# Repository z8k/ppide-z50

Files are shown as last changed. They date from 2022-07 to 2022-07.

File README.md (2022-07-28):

# ppide-z50
PPIDE card for Z50Bus

Heavily based on https://github.com/electrified/rc2014-82c55-ide

Intended for use with a horizontal-mounting 44-pin IDE Disk-On-Module module, this card omits the 40-pin IDE connector and external power input jack.

Notes:
1. Address selection is with the jumper pins in the lower right. Address bits A1 and A0 are ignored. Set to 0x20 (one jumper, on pin A5) for use with RomWBW and/or Fuzix.
2. You may wish to lower the value of R101 or use a super-bright LED if the disk activity light is a bit dim.

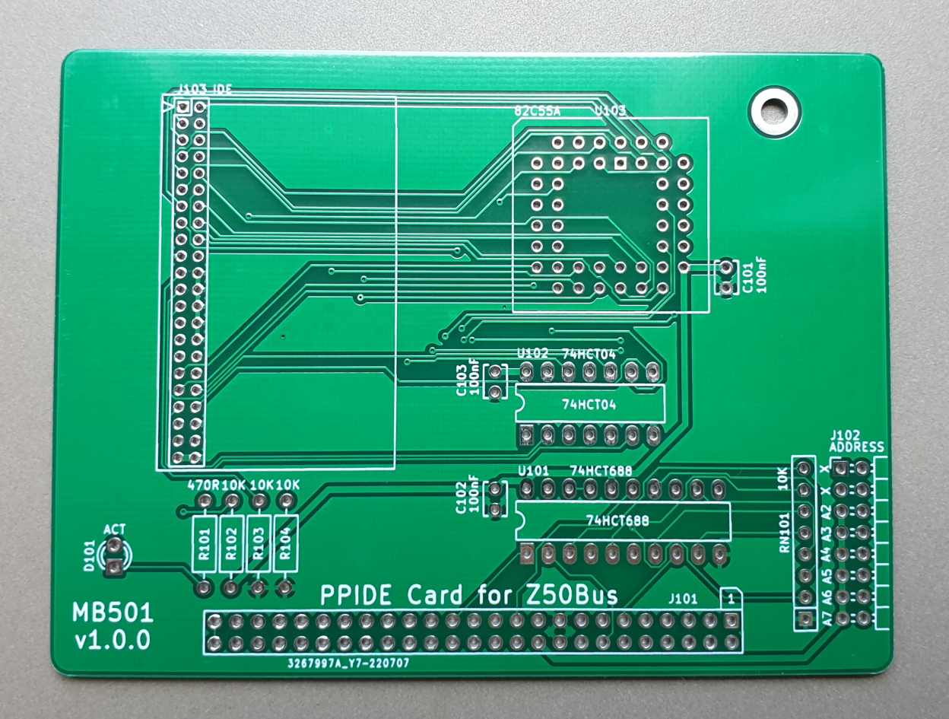
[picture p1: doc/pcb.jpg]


| Reference |  Value |
|---|---|
| R101 | 470R resistor or lower value suitable for your LED |
| R102 | 10K resistor |
| R103 | 10K resistor |
| R104 | 10K resistor |
| C101 | 0.1uF ceramic capacitor |
| C102 | 0.1uF ceramic capacitor |
| C103 | 0.1uF ceramic capacitor |
| RN101 | 10K SIP resistor (8 pins, 7 resistors) |
| D101 | LED |
| U101 | 74HCT688 |
| U102 | 74HCT04 |
| U103 | 82C55A (PLCC package) |
| J101 | 2x25 2.54mm right-angle male box header |
| J102 | 2x8 2.54mm pitch right-angle pin header |
| J103 | 2x22 2mm pitch pin header |

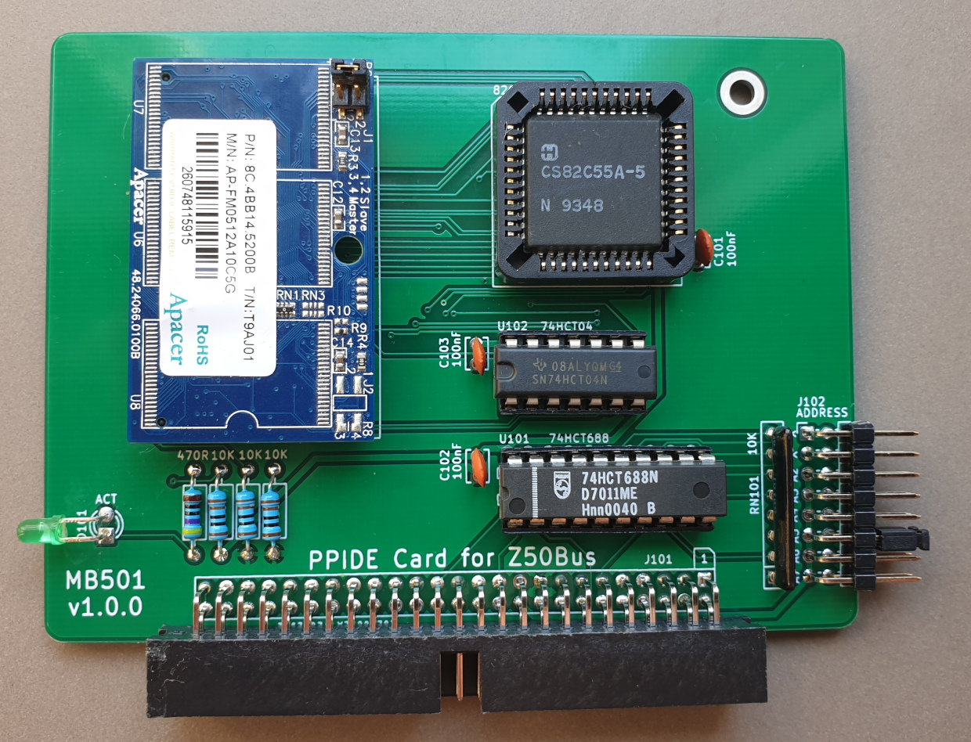
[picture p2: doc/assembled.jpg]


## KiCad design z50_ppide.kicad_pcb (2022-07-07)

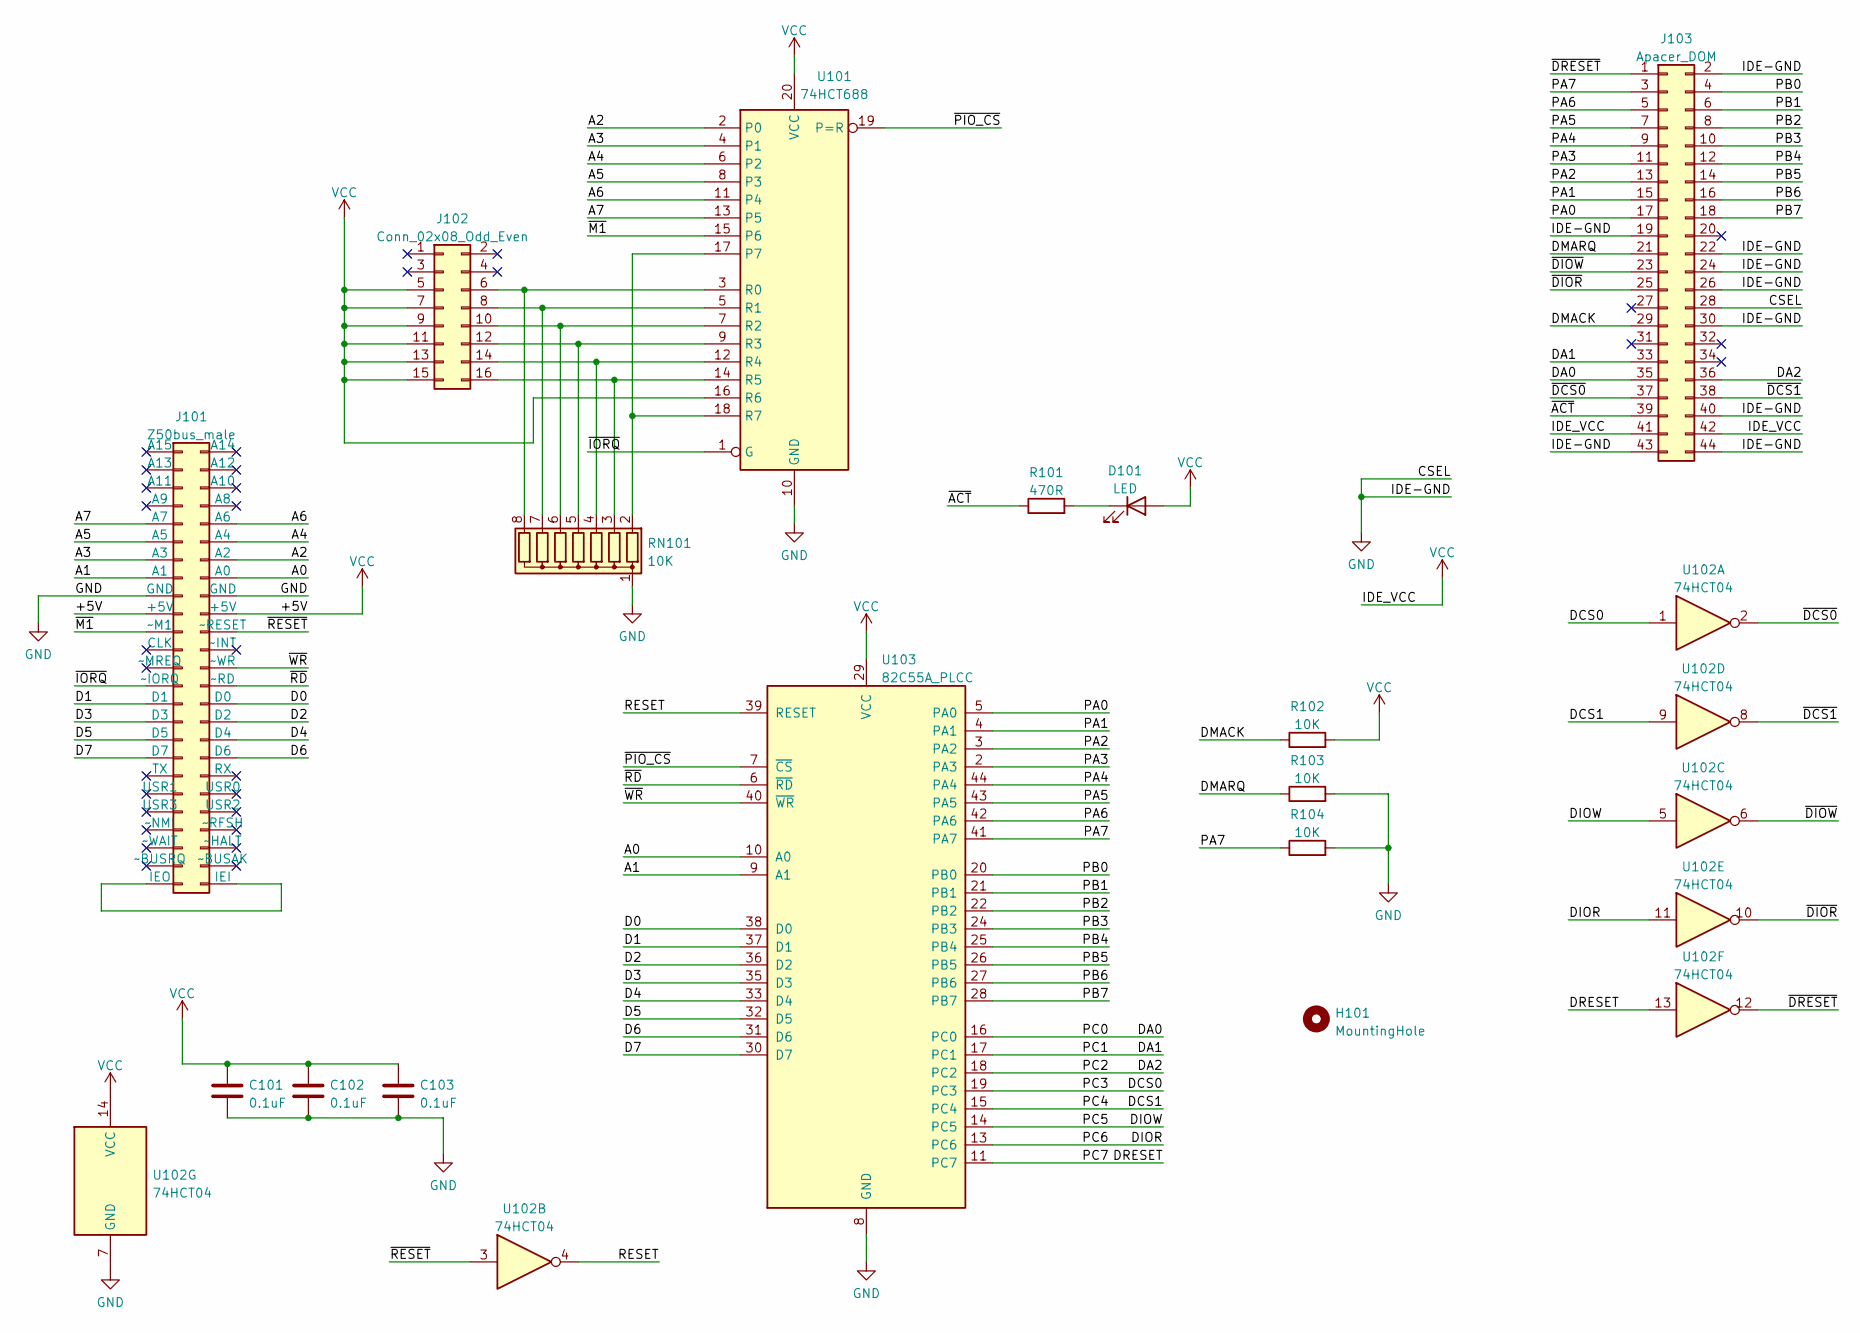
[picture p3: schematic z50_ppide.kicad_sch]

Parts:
C101, C102, C103: 0.1uF; C_Disc_D3.8mm_W2.6mm_P2.50mm
D101: LED; LED_D3.0mm
H101: MountingHole; MountingHole_3.2mm_M3_DIN965_Pad_TopBottom
J101: Z50bus_male; Z50bus module card edge
J102: Conn_02x08_Odd_Even; PinHeader_2x08_P2.54mm_Horizontal
J103: Apacer_DOM; Apacer DOM
R101: 470R; R_Axial_DIN0207_L6.3mm_D2.5mm_P10.16mm_Horizontal
R102, R103, R104: 10K; R_Axial_DIN0207_L6.3mm_D2.5mm_P10.16mm_Horizontal
RN101: 10K; R_Array_SIP8
U101: 74HCT688; DIP-20_W7.62mm_LongPads
U102: 74HCT04; DIP-14_W7.62mm_LongPads
U103: 82C55A_PLCC; PLCC-44_THT-Socket

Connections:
/A0: J101.16 (A0), U103.10 (A0)
/A1: J101.15 (A1), U103.9 (A1)
/A2: J101.14 (A2), U101.2 (P0)
/A3: J101.13 (A3), U101.4 (P1)
/A4: J101.12 (A4), U101.6 (P2)
/A5: J101.11 (A5), U101.8 (P3)
/A6: J101.10 (A6), U101.11 (P4)
/A7: J101.9 (A7), U101.13 (P5)
/D0: J101.30 (D0), U103.38 (D0)
/D1: J101.29 (D1), U103.37 (D1)
/D2: J101.32 (D2), U103.36 (D2)
/D3: J101.31 (D3), U103.35 (D3)
/D4: J101.34 (D4), U103.33 (D4)
/D5: J101.33 (D5), U103.32 (D5)
/D6: J101.36 (D6), U103.31 (D6)
/D7: J101.35 (D7), U103.30 (D7)
/DA0: J103.35, U103.16 (PC0)
/DA1: J103.33, U103.17 (PC1)
/DA2: J103.36, U103.18 (PC2)
/DCS0: U102.1, U103.19 (PC3)
/DCS1: U102.9, U103.15 (PC4)
/DIOR: U102.11, U103.13 (PC6)
/DIOW: U102.5, U103.14 (PC5)
/DMACK: J103.29, R102.1
/DMARQ: J103.21, R103.1
/DRESET: U102.13, U103.11 (PC7)
/PA0: J103.17, U103.5 (PA0)
/PA1: J103.15, U103.4 (PA1)
/PA2: J103.13, U103.3 (PA2)
/PA3: J103.11, U103.2 (PA3)
/PA4: J103.9, U103.44 (PA4)
/PA5: J103.7, U103.43 (PA5)
/PA6: J103.5, U103.42 (PA6)
/PA7: J103.3, R104.1, U103.41 (PA7)
/PB0: J103.4, U103.20 (PB0)
/PB1: J103.6, U103.21 (PB1)
/PB2: J103.8, U103.22 (PB2)
/PB3: J103.10, U103.24 (PB3)
/PB4: J103.12, U103.25 (PB4)
/PB5: J103.14, U103.26 (PB5)
/PB6: J103.16, U103.27 (PB6)
/PB7: J103.18, U103.28 (PB7)
/RESET: U102.4, U103.39 (RESET)
/~ACT: J103.39, R101.1
/~DCS0: J103.37, U102.2
/~DCS1: J103.38, U102.8
/~DIOR: J103.25, U102.10
/~DIOW: J103.23, U102.6
/~DRESET: J103.1, U102.12
/~IORQ: J101.27 (~IORQ), U101.1 (G)
/~M1: J101.21 (~M1), U101.15 (P6)
/~PIO_CS: U101.19 (P=R), U103.7 (~CS)
/~RD: J101.28 (~RD), U103.6 (~RD)
/~RESET: J101.22 (~RESET), U102.3
/~WR: J101.26 (~WR), U103.40 (~WR)
GND: C101.2, C102.2, C103.2, J101.17 (GND), J101.18 (GND), J103.2, J103.19, J103.22, J103.24, J103.26, J103.28, J103.30, J103.40, J103.43, J103.44, R103.2, R104.2, RN101.1 (common), U101.10 (GND), U102.7 (GND), U103.8 (GND)
unnamed: D101.1 (K), R101.2
unnamed: J101.49 (IEO), J101.50 (IEI)
unnamed: J102.6, RN101.8 (R7), U101.3 (R0)
unnamed: J102.8, RN101.7 (R6), U101.5 (R1)
unnamed: J102.10, RN101.6 (R5), U101.7 (R2)
unnamed: J102.12, RN101.5 (R4), U101.9 (R3)
unnamed: J102.14, RN101.4 (R3), U101.12 (R4)
unnamed: J102.16, RN101.3 (R2), U101.14 (R5)
unnamed: RN101.2 (R1), U101.17 (P7), U101.18 (R7)
VCC: C101.1, C102.1, C103.1, D101.2 (A), J101.19 (+5V), J101.20 (+5V), J102.5, J102.7, J102.9, J102.11, J102.13, J102.15, J103.41, J103.42, R102.2, U101.16 (R6), U101.20 (VCC), U102.14 (VCC), U103.29 (VCC)

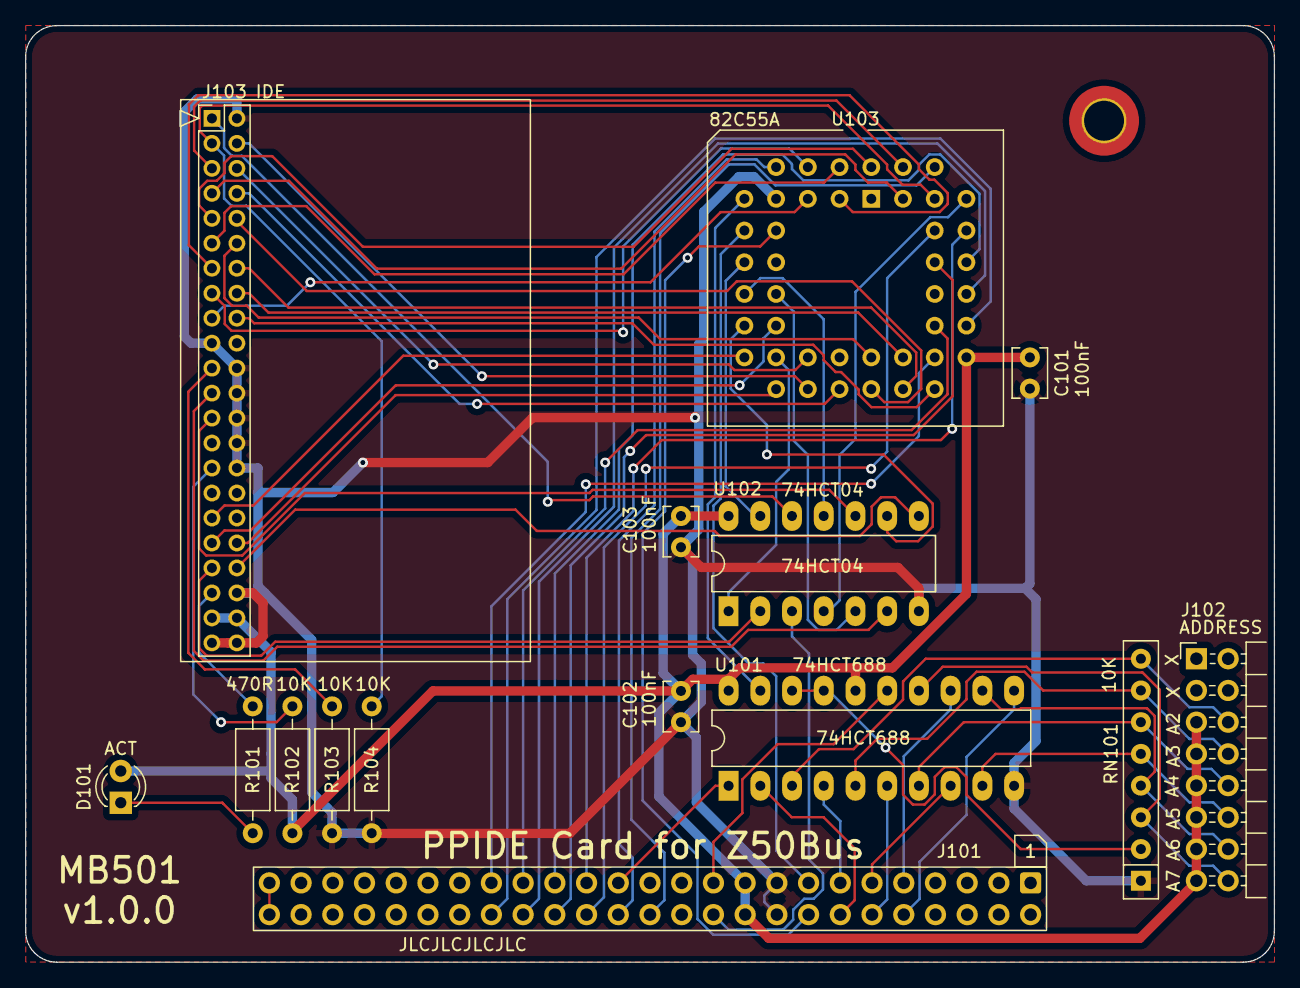
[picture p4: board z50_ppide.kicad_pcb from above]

Board: 2 copper layers, 100.0 x 75.0 mm, 16 parts (0 on the bottom side), 66 nets.

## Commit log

2022-07-07 V1.0.0 schematic and PCB layout
    [z50_ppide.kicad_pcb, z50_ppide.kicad_sch]
2022-07-07 V1.0.0 gerbers as sent to JLCPCB
    [z50_ppide-B_Cu.gbr, z50_ppide-B_Mask.gbr, z50_ppide-B_Silkscreen.gbr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]
2022-07-20 Add board image
2022-07-28 Add image of assembled card
